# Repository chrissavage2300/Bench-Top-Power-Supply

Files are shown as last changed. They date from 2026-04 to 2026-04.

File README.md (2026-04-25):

# Bench-Top-Power-Supply
An Adjustable linear powersupply using the PIC16F1778 with current limiting. Program is done in Great Cow Basic. The schematic was done in Eagle CAD.

Features: 

GLCD:ST7735 but it could easily be a smaller one.

Adjustable Current Limit using encoders.

Adjustable Voltage using encoders.

Clicking the Voltage Adjust knob inward selects either a x1 or x10 multiplier to make adjustment faster. 

Clicking the Current Adjust knob switches between two pre-set voltages, 3.3V and 5V.

The PIC is mostly for displaying voltage and current. The actual control is all done by the op-amp

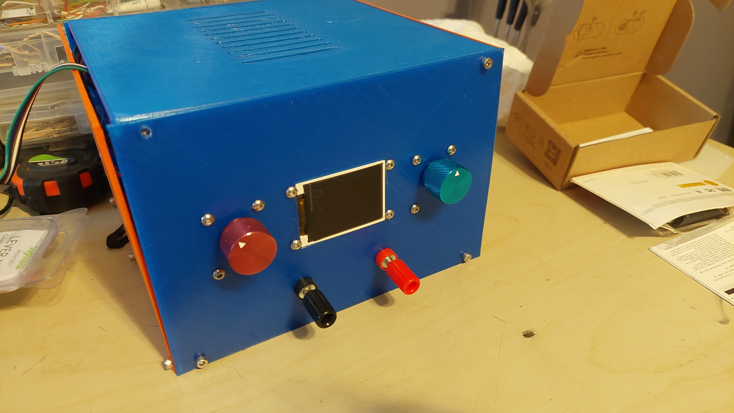
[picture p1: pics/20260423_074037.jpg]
Power Supply


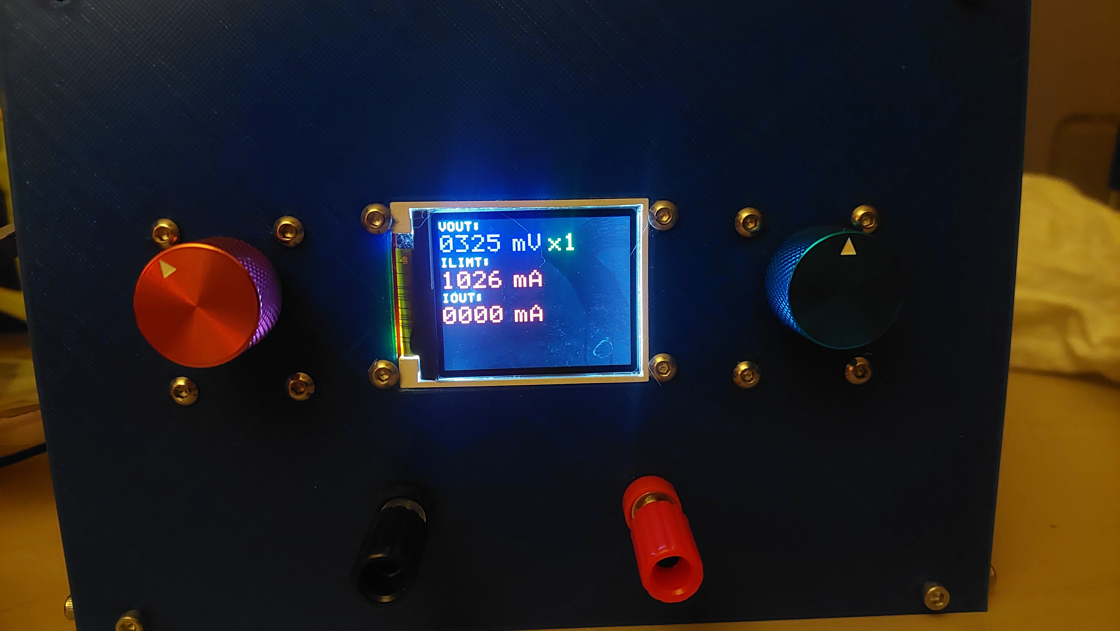
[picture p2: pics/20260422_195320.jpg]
Power Supply GLCD ON


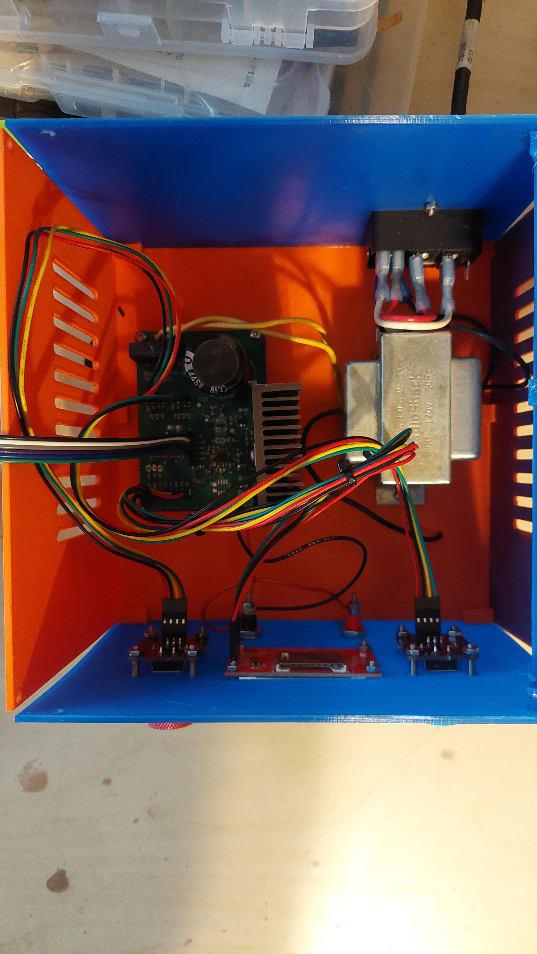
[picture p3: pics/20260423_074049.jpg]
Power Supply Board


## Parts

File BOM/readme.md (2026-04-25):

10/11/2021-Original commit. Changed PIC to be the same family but larger memory.

4/24/2026 Update: I changed out the TIP41C to a TIP120G. The schematic has the most up to date parts but this is the only major change.

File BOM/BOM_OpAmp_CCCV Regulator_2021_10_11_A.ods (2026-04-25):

Part | Value | Device | Package | Description
B1 | RECTIFIER-KBU | RECTIFIER-KBU | KBU | Rectifier | stock
C1 | 10uF | CAP1206 | 1206 | Capacitor | ‎1253-CM316X7R106M25ATCT-ND‎
C2 | 4.7uF | CAP1206 | 1206 | Capacitor | ‎1276-3177-1-ND‎ (https://www.digikey.com/product-detail/en/CL31B475KAHNFNE/1276-3177-1-ND/3891263?itemSeq=370521257)
C3 | 1nF | CAP0805 | 805 | Capacitor | 478-10836-1-ND
C4 | 0.1uF | CAP1206 | 1206 | Capacitor | 1276-1017-1-ND
C5 | 15pf | CAP0805 | 805 | Capacitor | 478-11902-1-ND
C6 | 1nF | CAP0805 | 805 | Capacitor | 478-10836-1-ND
C7 | 0.1uF | CAP0805 | 805 | Capacitor | 1276-1020-1-ND
C8 | 100nF | CAP1206 | 1206 | Capacitor | 1276-1017-1-ND
C11 | 12,000uf | CPOL-USE10-25 | EB25D | POLARIZED CAPACITOR, American symbol | ‎338-3805-ND‎
DISPLAY | 1.8 | TFT | DISPLAY" | M08LOCK_LONGPADS | Stock
ENC1 |  | M04LOCK_LONGPADS | 1X04_LOCK_LONGPADS | ‎PEC12R-4020F-S0024‎ | ‎PEC11R-4215F-S0024‎
ENC2 |  | M04LOCK_LONGPADS | 1X04_LOCK_LONGPADS | ‎PEC12R-4020F-S0024‎ | ‎PEC11R-4215F-S0024‎
IC1 | TLV2172IDR | TLV2171IDR | SOIC8 | Op-Amp | 296-47385-1-ND‎ (https://www.digikey.com/product-detail/en/TLV2172IDR/296-47385-1-ND/7688578?itemSeq=368264656) | OR TLV9302IDR (296-53513-1-ND)
IC2 | TLV2172IDR | TLV2171IDR | SOIC8 | Op-Amp | 296-47385-1-ND‎ (https://www.digikey.com/product-detail/en/TLV2172IDR/296-47385-1-ND/7688578?itemSeq=368264656) | OR TLV9302IDR (296-53513-1-ND)
IC3 | INA180A1IDBVR | INA180A1IDBVR | SOIC8 | Current Sense | ‎INA180A1IDBVR‎ | OR TSC888AILT(497-8269-1-ND)
IC5 | LM334M | LM334M | SO08 | 3-Terminal Adjustable Current Sources | ‎LM334MX/NOPBCT-ND‎ (https://www.digikey.com/product-detail/en/LM334MX%2FNOPB/LM334MX%2FNOPBCT-ND/4988724?itemSeq=368264659)
IC6 | AS78L05RTR-E1 | 78L05F | SOT89 | POSITOIV-VOLTAGE REGULATORS | Stock | MC78L05ACHT1G
JP1 | M023.5MM_LOCK | M023.5MM_LOCK | SCREWTERMINAL-3.5MM-2_LOCK | Standard 2-pin 0.1 | Stock
JP2 | M023.5MM | M023.5MM | SCREWTERMINAL-3.5MM-2 | Standard 2-pin 0.1 | Stock
JP3 | FAN | M02POLAR_LOCK | MOLEX-1X2_LOCK | Standard 2-pin 0.1 | Stock
JP4 | TEMP_SENSE | M02PTH | 1X02 | Standard 2-pin 0.1 | Stock
LED1 | RED | LED1206 | LED-1206 | LEDs | Stock
PRG |  | M05LOCK | 1X05_LOCK | Header 5 | Stock
Q1 | TIP120G | TIP120G | TO220AV | NPN TRANSISTOR
Q2 | IRLML6344TRPBF | MOSFET-NCHANNEL2N7002PW | SOT323 | IRLML6344TRPBF | IRLML6344TRPBF
Q3 |  | TRANSISTOR_NPNSOT23 | SOT23 | Generic NPN BJT | MMBT3904 | stock
R1 | 1.47k | RESISTOR1206 | 1206 | Resistor | ‎311-1.47KFRCT-ND‎
R2 | 10k | RESISTOR1206 | 1206 | Resistor | ‎RC1206FR-0710KL‎
R3 | 1.5k | RESISTOR1206 | 1206 | Resistor | ‎311-1.50KFRCT-ND‎ (https://www.digikey.com/product-detail/en/RC1206FR-071K5L/311-1.50KFRCT-ND/731388?itemSeq=370475846)
R4 | 100k | RESISTOR0805-RES | 805 | Resistor | RR12P100KDCT-ND
R5 | 0.1 | RESISTOR1206 | 1206 | Resistor | ‎CSR1206FTR100CT-ND‎ (https://www.digikey.com/product-detail/en/CSR1206FTR100/CSR1206FTR100CT-ND/3477073?itemSeq=370523357)
R6 | 0.1 | RESISTOR1206 | 1206 | Resistor | ‎CSR1206FTR100CT-ND‎ (https://www.digikey.com/product-detail/en/CSR1206FTR100/CSR1206FTR100CT-ND/3477073?itemSeq=370523357)
R7 | 13 | RESISTOR1206 | 1206 | Resistor | RC1206FR-0713RL
R8 | 2k | RESISTOR0805-RES | 805 | Resistor | ‎2019-RK73H2ATTD2001FCT-ND‎
R9 | 2k | RESISTOR0805-RES | 805 | Resistor | ‎2019-RK73H2ATTD2001FCT-ND‎
R10 | 2k | RESISTOR0805-RES | 805 | Resistor | ‎2019-RK73H2ATTD2001FCT-ND‎
R11 | 300 | RESISTOR0805-RES | 805 | Resistor | RR12P300DCT-ND
R12 | 300 | RESISTOR0805-RES | 805 | Resistor | RR12P300DCT-ND
R14 | 2k | RESISTOR0805-RES | 805 | Resistor | ‎2019-RK73H2ATTD2001FCT-ND‎
R15 | 2k | RESISTOR0805-RES | 805 | Resistor | ‎2019-RK73H2ATTD2001FCT-ND‎
R16 | 2k | RESISTOR0805-RES | 805 | Resistor | ‎2019-RK73H2ATTD2001FCT-ND‎
R20 | 10k | RESISTOR1206 | 1206 | Resistor | stock
R21 | 1.3k | RESISTOR1206 | 1206 | Resistor | stock
TS sensor |  |  | ‎NTCALUG03A103G‎
U3 | PIC16F1778-X/SO | PIC16F1778-X/SO | SOIC28-W_MC |  | PIC16F1778-X/SO
UART |  | M03LOCK_LONGPADS | 1X03_LOCK_LONGPADS | Header 3
VREF | ADR5040ARTZ-REEL7 | ADR5040ARTZ-REEL7 | RT_3_ADI |  | ‎ADR5040ARTZ-REEL7‎
 | Power Receptable |  |  | 719W-00/04 | 719W-00/04
 | Binding Posts |  |  | PRT-09739 | PRT-09739
 | Binding Posts |  |  | PRT-09740 | PRT-09740
 | Encoder connector |  |  |  | STOCK | 1597-1502-ND

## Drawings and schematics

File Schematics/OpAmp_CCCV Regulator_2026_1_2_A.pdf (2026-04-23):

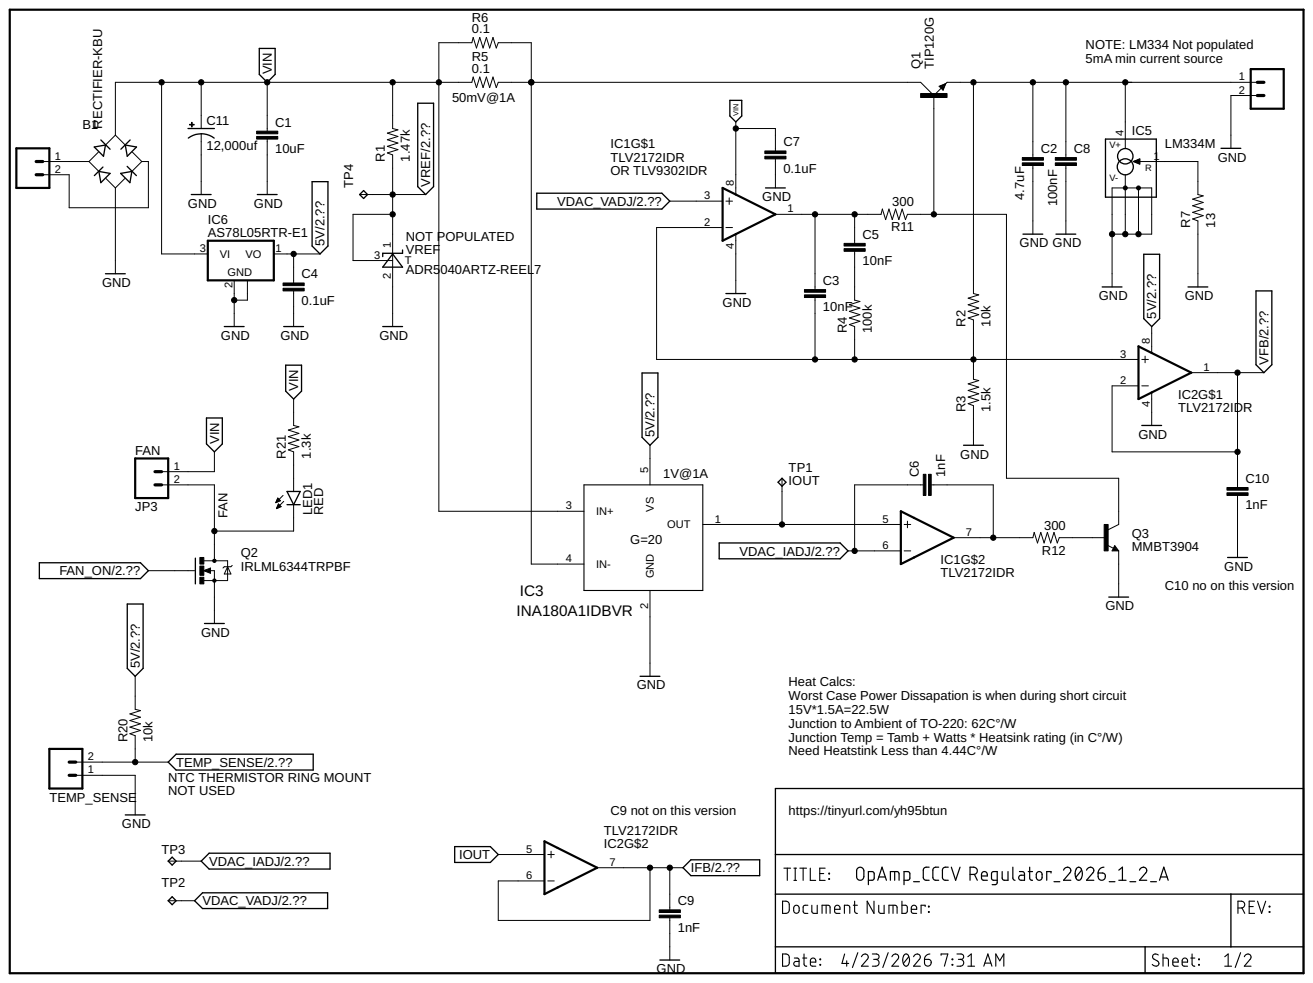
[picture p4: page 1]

C10 no on this version

Heat Calcs: Worst Case Power Dissapation is when during short circuit

Junction to Ambient of TO-220: 62C°/W
Junction Temp = Tamb + Watts * Heatsink rating (in C°/W)
Need Heatstink Less than 4.44C°/W

TEMP_SENSE/2.??
NTC THERMISTOR RING MOUNT
NOT USED

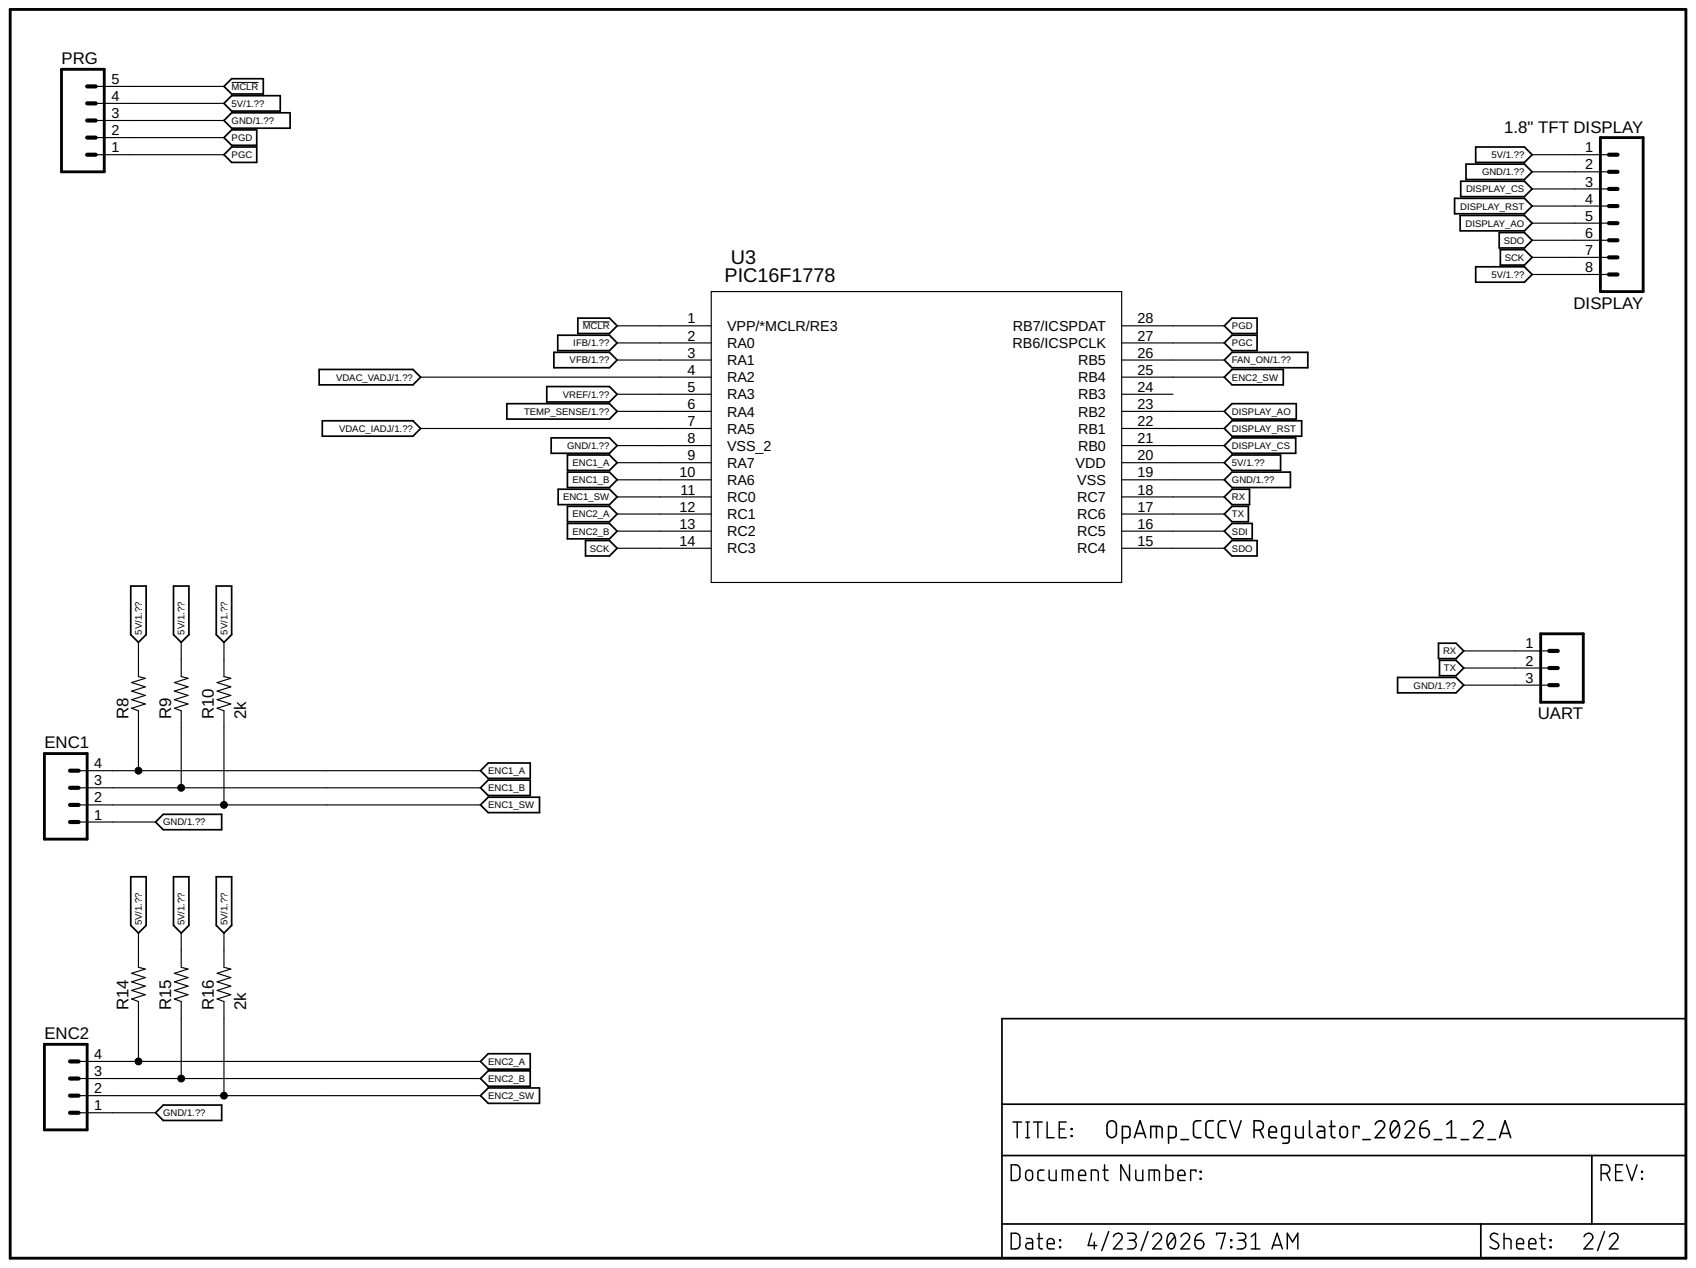
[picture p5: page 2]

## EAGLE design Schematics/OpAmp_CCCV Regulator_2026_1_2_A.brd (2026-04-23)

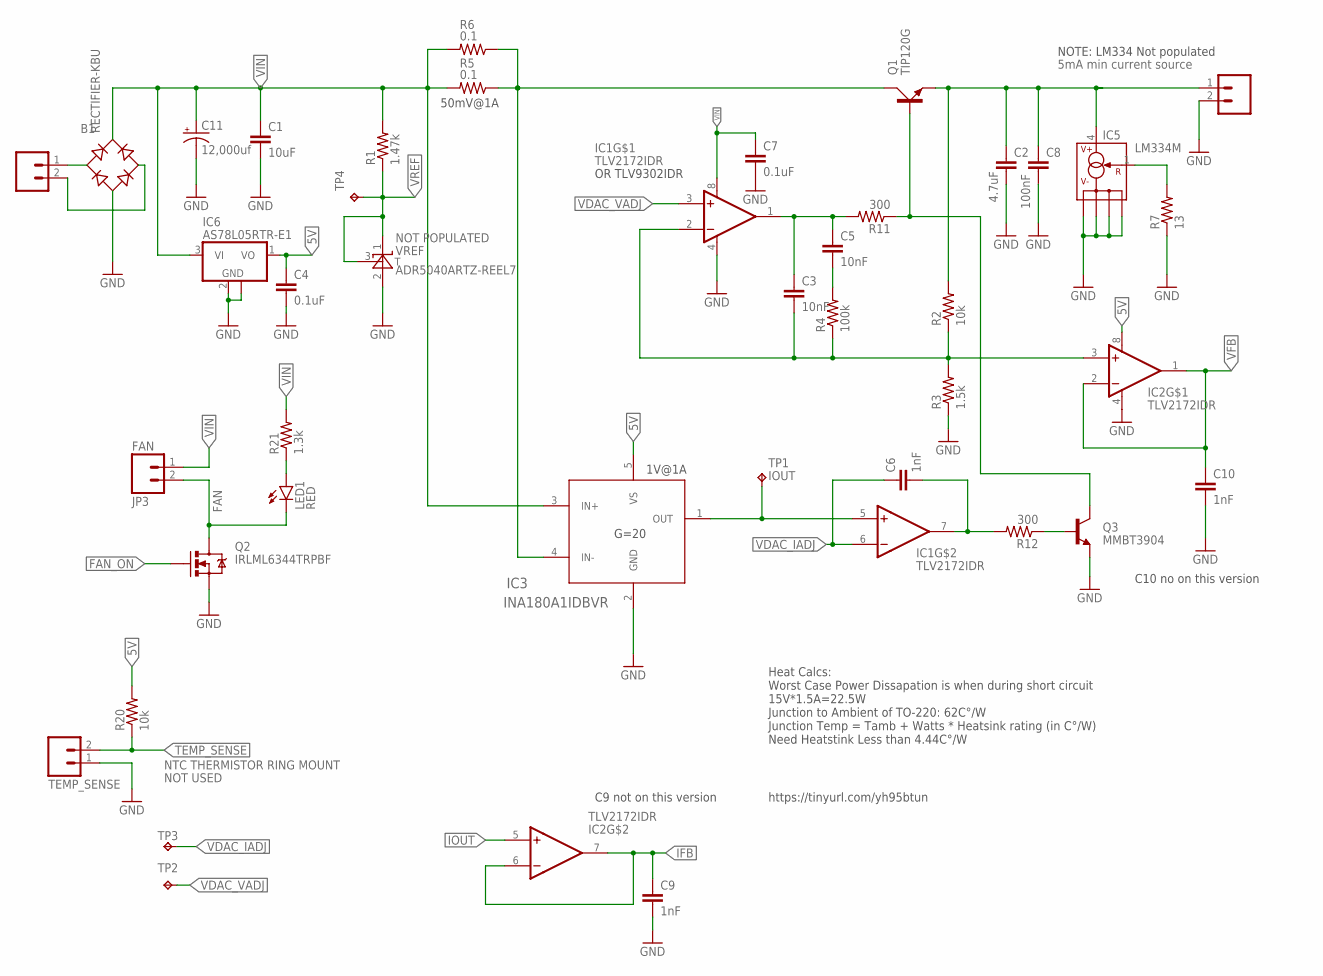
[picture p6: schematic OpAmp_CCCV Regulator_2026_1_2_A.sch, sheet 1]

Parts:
B1: RECTIFIER-KBU; KBU
C1: 10uF; 1206
C2: 4.7uF; 1206
C3, C5: 10nF; 0805
C4: 0.1uF; 1206
C6, C9, C10: 1nF; 0805
C7: 0.1uF; 0805
C8: 100nF; 1206
C11: 12,000uf; EB25D
IC1, IC2: TLV2172IDR; SOIC8
IC3: INA180A1IDBVR; DBV0005A_N
IC5: LM334M; SO08
IC6: AS78L05RTR-E1; SOT89
JP1: M023.5MM_LOCK; SCREWTERMINAL-3.5MM-2_LOCK
JP2: M023.5MM; SCREWTERMINAL-3.5MM-2
JP3: FAN; MOLEX-1X2_LOCK
JP4: TEMP_SENSE; 1X02
LED1: RED; LED-1206
Q1: TIP120G; TO220AV
Q2: IRLML6344TRPBF; SOT323
Q3: MMBT3904; SOT23
R1: 1.47k; 1206
R2, R20: 10k; 1206
R3: 1.5k; 1206
R4: 100k; 0805
R5, R6: 0.1; 1206
R7: 13; 1206
R11, R12: 300; 0805
R21: 1.3k; 1206
TP1, TP2, TP3, TP4: TPTP20R; TP20R
VREF: ADR5040ARTZ-REEL7; RT_3_ADI

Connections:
5V: C4.1, IC2.8 (V+), IC3.5 (VS), IC6.1 (VO), R20.2; also elsewhere on the board
AC: B1.AC1, JP1.1
COMP: C3.1, C5.1, IC1.1 (OUT), R11.2
FAN: JP3.2, LED1.C, Q2.3 (D)
FAN_ON: Q2.1 (G); also elsewhere on the board
FB: C3.2, IC1.2 (-IN), IC2.3 (+IN), R2.1, R3.2, R4.1
GND: B1.-, C1.2, C2.2, C4.2, C7.2, C8.2, C9.2, C10.2, C11.-, IC1.4 (V-), IC2.4 (V-), IC3.2 (GND), IC5.2 (V-), IC5.3 (V-), IC5.6 (V-), IC5.7 (V-), IC6.2 (GND), IC6.2@1 (GND), JP2.2, JP4.1, Q2.2 (S), Q3.2 (E), R3.1, R7.1, VREF.2 (A); also elsewhere on the board
IFB: C9.1, IC2.6 (-IN), IC2.7 (OUT); also elsewhere on the board
IOUT: IC1.5 (+IN), IC2.5 (+IN), IC3.1 (OUT), TP1.TP
IOUTA: C6.2, IC1.7 (OUT), R12.2
unnamed: C5.2, R4.2
unnamed: B1.AC2, JP1.2
unnamed: IC5.1 (R), R7.2
unnamed: Q3.1 (B), R12.1
unnamed: LED1.A, R21.1
PASS_BASE: Q1.B, Q3.3 (C), R11.1
TEMP_SENSE: JP4.2, R20.1; also elsewhere on the board
VDAC_IADJ: C6.1, IC1.6 (-IN), TP3.TP; also elsewhere on the board
VDAC_VADJ: IC1.3 (+IN), TP2.TP; also elsewhere on the board
VFB: C10.1, IC2.1 (OUT), IC2.2 (-IN); also elsewhere on the board
VIN: B1.+, C1.1, C7.1, C11.+, IC1.8 (V+), IC3.3 (IN+), IC6.3 (VI), JP3.1, R1.2, R5.2, R6.2, R21.2
VIN2: IC3.4 (IN-), Q1.C, R5.1, R6.1
VOUT: C2.1, C8.1, IC5.4 (V+), JP2.1, Q1.E, R2.2
VREF: R1.1, TP4.TP, VREF.1 (C), VREF.3 (T); also elsewhere on the board

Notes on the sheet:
G=20
50mV@1A
1V@1A
https://tinyurl.com/yh95btun
5mA min current source
Heat Calcs: Worst Case Power Dissapation is when during short circuit 15V*1.5A=22.5W Junction to Ambient of TO-220: 62C°/W Junction Temp = Tamb + Watts * Heatsink rating (in C°/W) Need Heatstink Less than 4.44C°/W
NTC THERMISTOR RING MOUNT
OR TLV9302IDR
NOTE: LM334 Not populated
C9 not on this version
C10 no on this version
NOT POPULATED
NOT USED

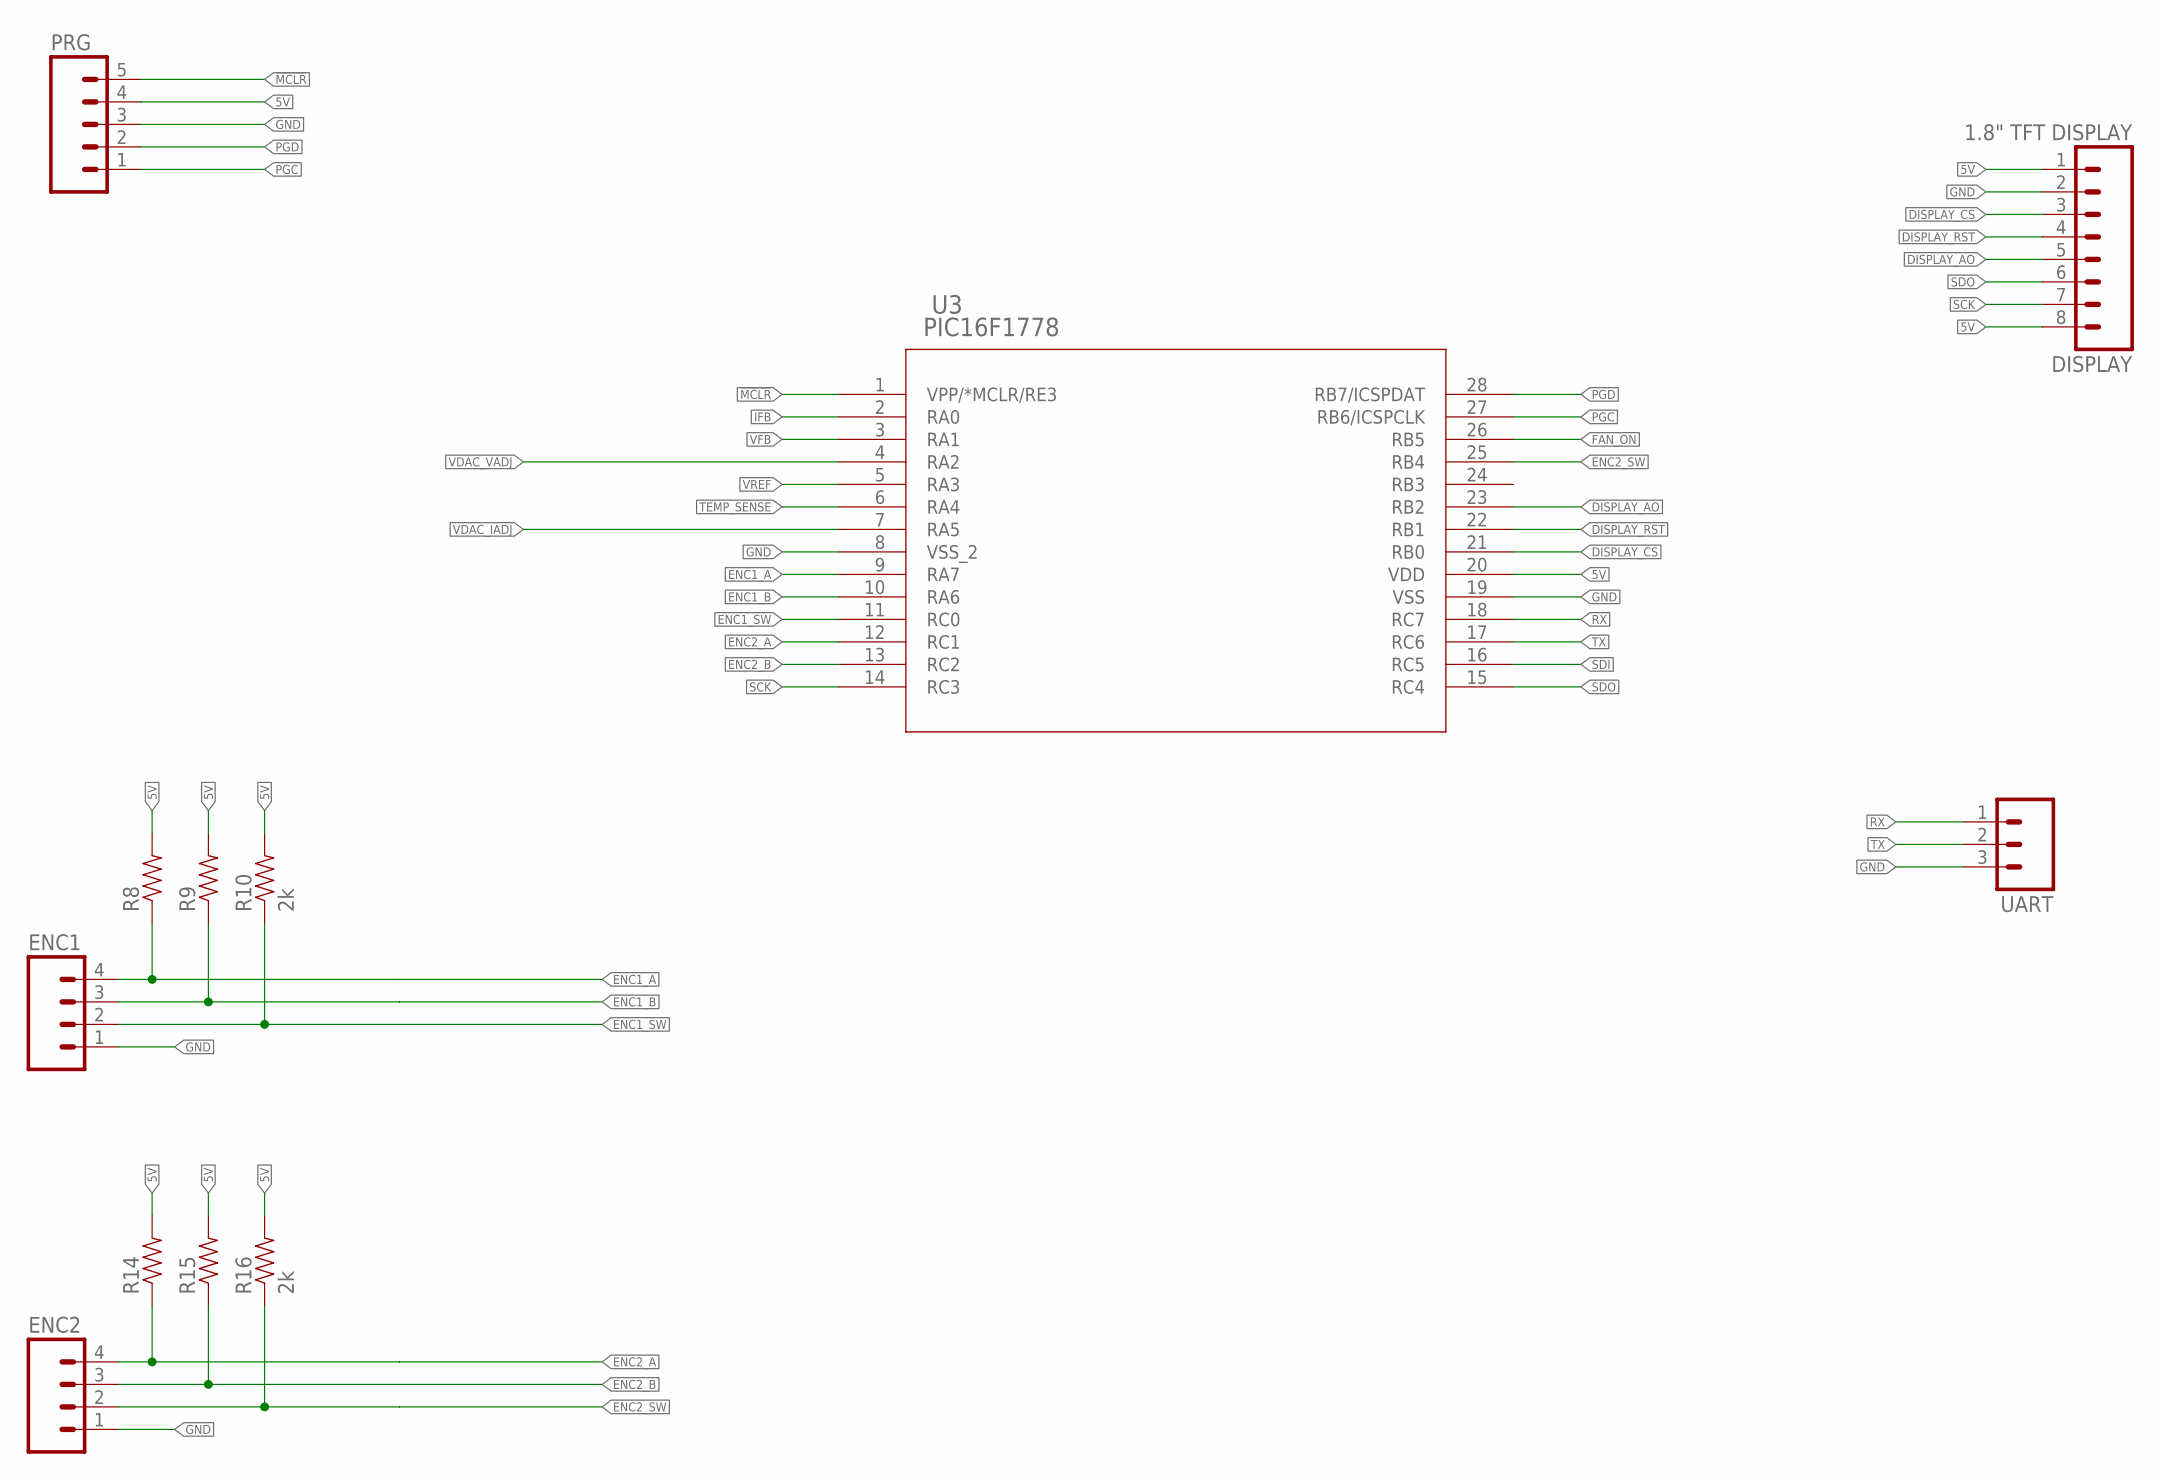
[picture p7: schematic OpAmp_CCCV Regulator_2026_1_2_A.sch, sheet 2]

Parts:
DISPLAY: 1.8" TFT DISPLAY; 1X08_LOCK_LONGPADS
ENC1, ENC2: M04LOCK_LONGPADS; 1X04_LOCK_LONGPADS
PRG: M05LOCK; 1X05_LOCK
R8, R9, R10, R14, R15, R16: 2k; 0805
U3: PIC16F1778; SOIC28-W_MC
UART: M03LOCK_LONGPADS; 1X03_LOCK_LONGPADS

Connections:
5V: DISPLAY.1, DISPLAY.8, PRG.4, R8.2, R9.2, R10.2, R14.2, R15.2, R16.2, U3.20 (VDD); also elsewhere on the board
!MCLR: PRG.5, U3.1 (VPP/*MCLR/RE3)
DISPLAY_AO: DISPLAY.5, U3.23 (RB2)
DISPLAY_CS: DISPLAY.3, U3.21 (RB0)
DISPLAY_RST: DISPLAY.4, U3.22 (RB1)
ENC1_A: ENC1.4, R8.1, U3.9 (RA7)
ENC1_B: ENC1.3, R9.1, U3.10 (RA6)
ENC1_SW: ENC1.2, R10.1, U3.11 (RC0)
ENC2_A: ENC2.4, R14.1, U3.12 (RC1)
ENC2_B: ENC2.3, R15.1, U3.13 (RC2)
ENC2_SW: ENC2.2, R16.1, U3.25 (RB4)
FAN_ON: U3.26 (RB5); also elsewhere on the board
GND: DISPLAY.2, ENC1.1, ENC2.1, PRG.3, U3.8 (VSS_2), U3.19 (VSS), UART.3; also elsewhere on the board
IFB: U3.2 (RA0); also elsewhere on the board
PGC: PRG.1, U3.27 (RB6/ICSPCLK)
PGD: PRG.2, U3.28 (RB7/ICSPDAT)
RX: U3.18 (RC7), UART.1
SCK: DISPLAY.7, U3.14 (RC3)
SDI: U3.16 (RC5)
SDO: DISPLAY.6, U3.15 (RC4)
TEMP_SENSE: U3.6 (RA4); also elsewhere on the board
TX: U3.17 (RC6), UART.2
VDAC_IADJ: U3.7 (RA5); also elsewhere on the board
VDAC_VADJ: U3.4 (RA2); also elsewhere on the board
VFB: U3.3 (RA1); also elsewhere on the board
VREF: U3.5 (RA3); also elsewhere on the board

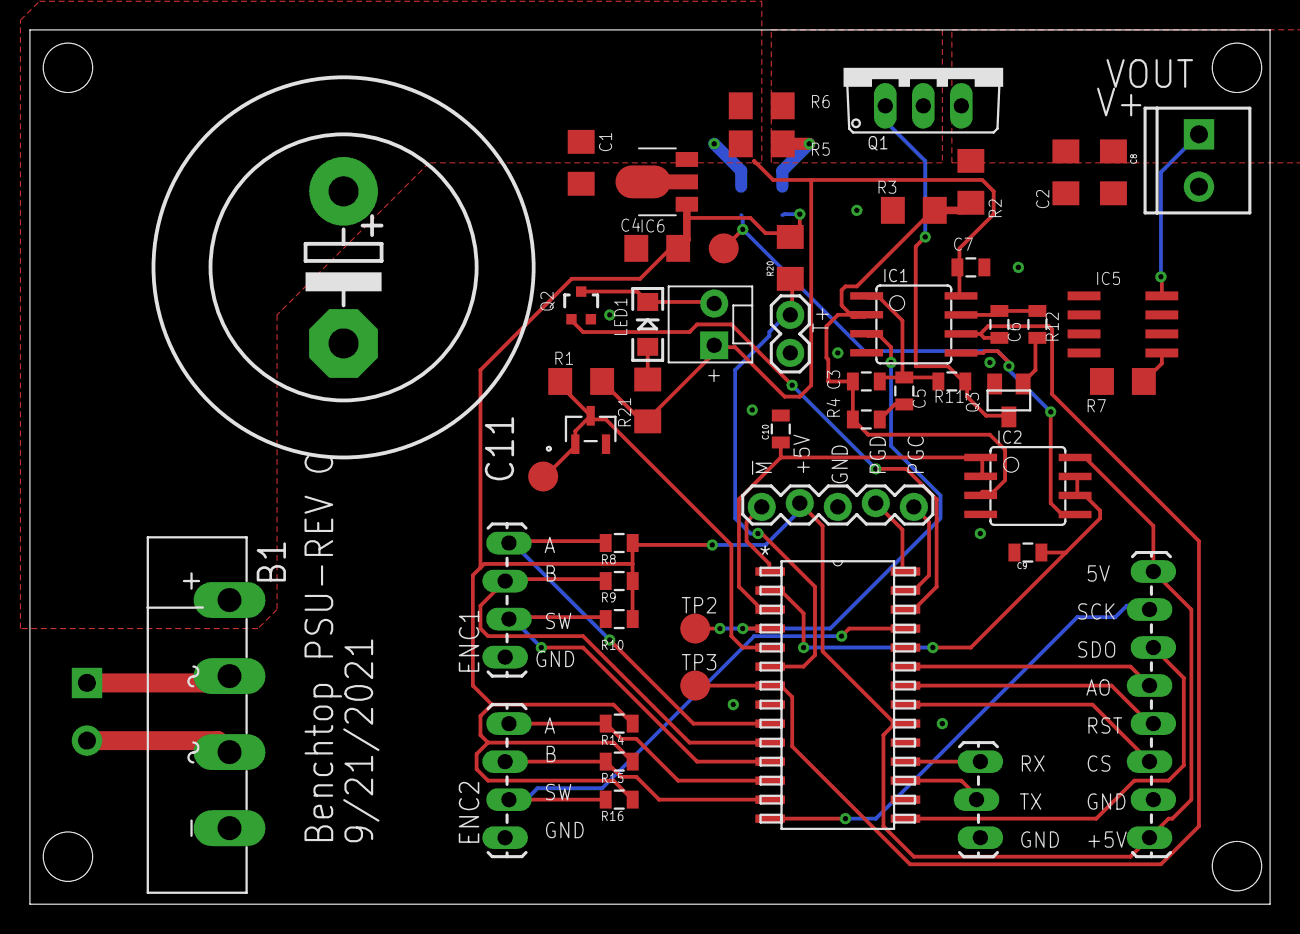
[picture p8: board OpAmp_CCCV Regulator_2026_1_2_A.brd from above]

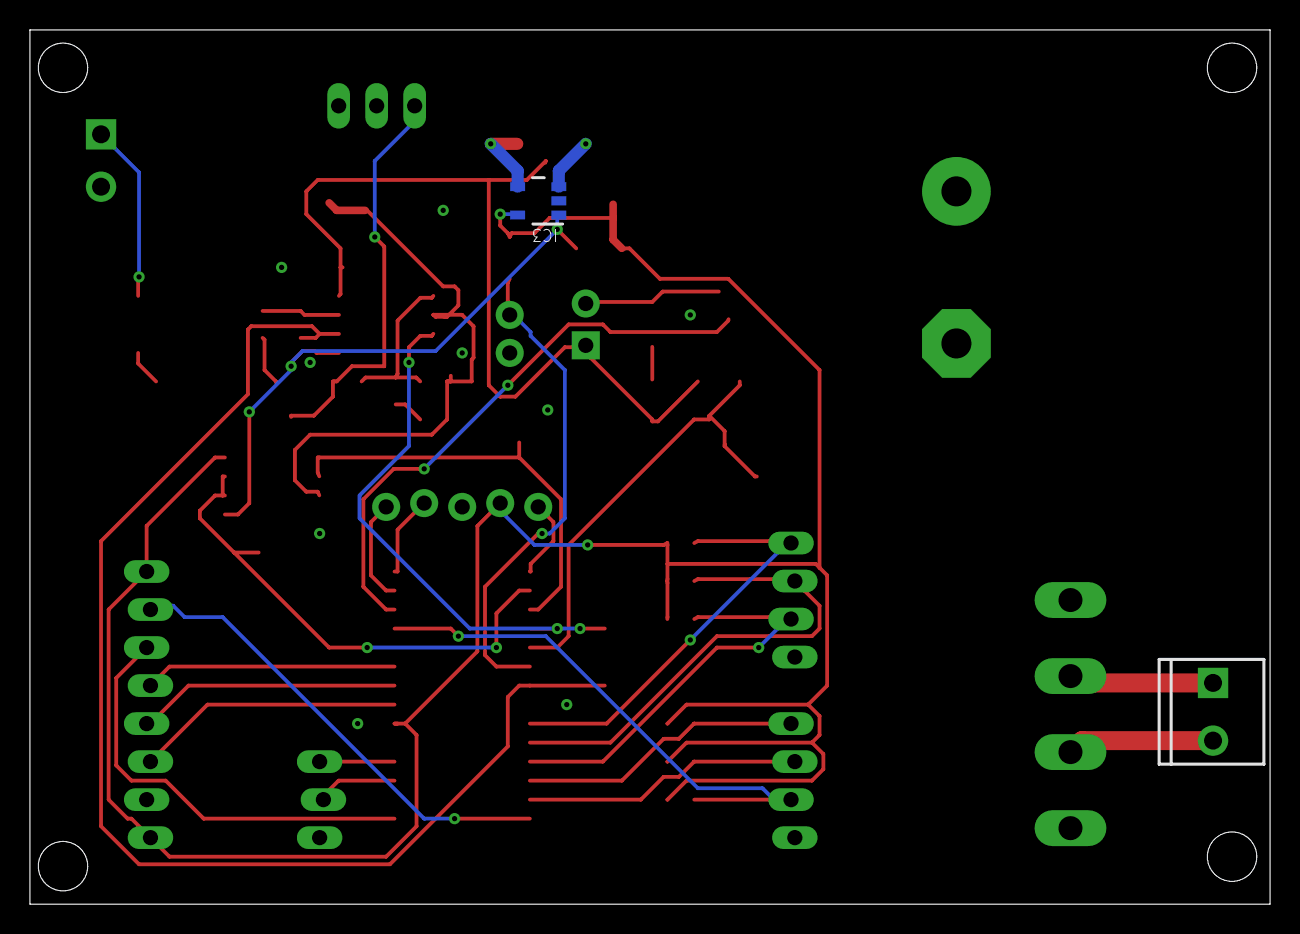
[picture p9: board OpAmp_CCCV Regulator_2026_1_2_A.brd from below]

Board: 2 copper layers, 82.9 x 58.4 mm, 53 parts (2 on the bottom side), 40 nets.

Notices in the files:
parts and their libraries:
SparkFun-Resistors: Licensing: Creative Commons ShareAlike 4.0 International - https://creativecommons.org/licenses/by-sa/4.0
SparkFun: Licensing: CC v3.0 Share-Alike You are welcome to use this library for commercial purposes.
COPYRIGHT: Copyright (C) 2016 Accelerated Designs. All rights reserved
